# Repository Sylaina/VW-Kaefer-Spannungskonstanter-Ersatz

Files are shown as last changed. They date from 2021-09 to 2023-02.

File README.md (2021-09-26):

# VW-Käfer Spannungskonstanter-Ersatz für die Tankanzeige

Die hier gezeigte Schaltung dient dem Ersatz des im VW Käfer eingesetzten Spannungskonstanter für die Tankanzeige.

Der Füllstand des Tanks im Käfer ist mehr eine Schätzung als eine gute Anzeige. Ich habe in der Vergangenheit verschiedene Tankgeber und Tankanzeigen ausprobiert aber nie war die Tankanzeige zufriedenstellend einzustellen. Nach genauerer Analyse der verwendeten Technik ist, meiner Meinung nach, das Anzeigeinstrument das Problem. Der Tankgeber wird so im Grunde sogar heute noch in PKWs eingesetzt, hier betätigt ein Schwimmer ein Potentiometer (kurz Poti) welches seinen Widerstandswert dadurch ändert. Das Poti ist in Reihe geschaltet mit der Tankanzeige. Über Poti und Tankanzeige liegt eine konstante Spannung, durch die Widerstandsänderung des Potis ändert sich somit der Strom durch Poti und Tankanzeige. Dieser Strom erwärmt die Tankanzeige was letzten Endes die Tanknadel im Instrument bewegt.
Bei mir war das Problem, dass ich entweder die Leerstellung oder die Vollstellung richtig einstellen konnte. Ich habe es aber nie geschafft, die Leer- und Voll-Stellung gleichzeitig richtig einzustellen.

# Was macht die Schaltung?

Die hier vorgestellte Schaltung ersetzt den originalen Spannungskonstanter und prägt dem Anzeigeinstrument, abhängig von der Potistellung des Tankgebers, einen konstanten Strom ein. Lediglich die Widerstandswerte des Potis für Leer, Reserve (~5l Tankfüllung) und Voll müssen ermittelt werden sowie der Strom, den das Anzeigeinstrument für den Zeigerausschlag auf Tank Voll und Tank Leer aufnimmt.

Die Schaltung misst mit einem Mikrocontroller (AVR ATtiny85) den Widerstand des Potis vom Tankgeber und wandelt diesen Widerstand in einen proportionalen Strom für die Tankanzeige um.

Als Zusatz kann man eine LED oder ähnliches verbauen um das Erreichen der Reservefüllung zu visualisieren.

# Wie installiert man die Schaltung

Man entfernt den alten Spannungskonstanter und baut die Schaltung an der Stelle ein, in der auch der Spannungskonstanter eingebaut war. Dann muss nur noch das Instrument, die Schaltung und der Tankgeber angeschlossen werden und schon sollte alles funktionieren. Das Programm für den Mikrocontroller sowie die Gerberfiles für die Platine findet ihr in diesem github.

Viel Spass beim Nachbauen

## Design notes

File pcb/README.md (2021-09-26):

# Schaltplan und Gerberfiles für die Platine

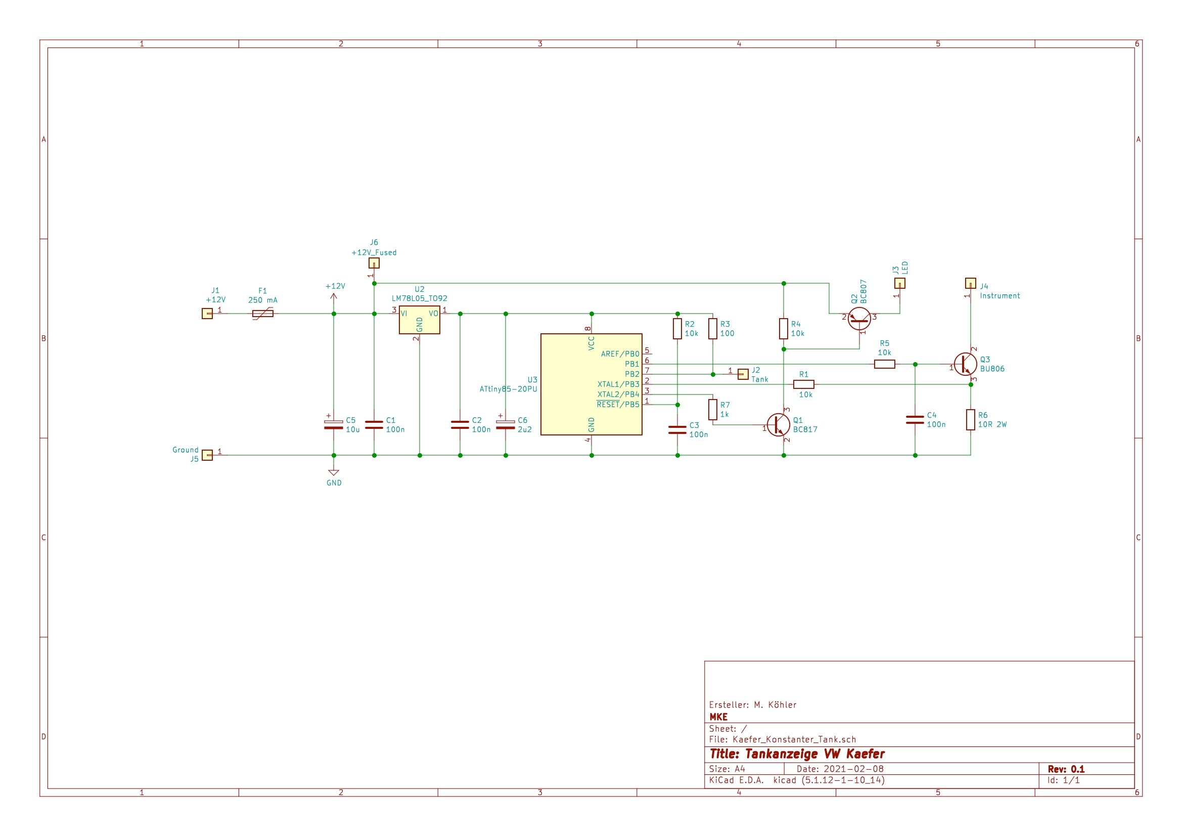
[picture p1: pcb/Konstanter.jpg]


# Preview der Platine

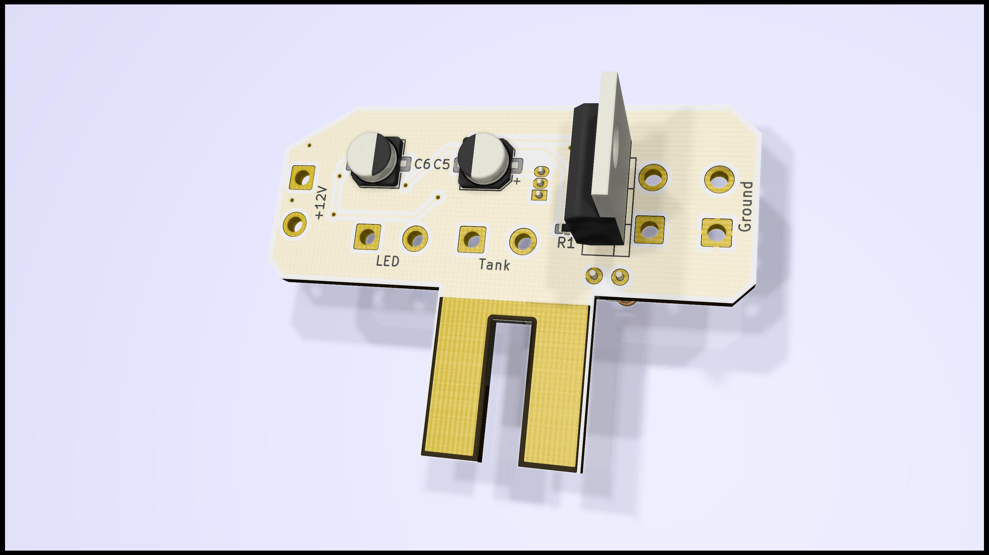
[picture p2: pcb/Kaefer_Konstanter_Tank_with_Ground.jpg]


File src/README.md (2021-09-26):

# Quellecode für den Mikrocontroller

Im makefile stehen alles nötigen Einstellungen um das Mikrocontrollerprogramm mit Hilfe des avr-gcc, avrdude 
und einem USBTiny auf einen ATtiny85 zu flashen.

# main.h

Das ist das einzige File, dass angefasst werden muss. In der Headerdatei werden die Widerstände des Potis
für die unterschiedlichen Tankfüllstände sowie die Ströme des Anzeigeninstruments festgelegt. Genaueres 
steht in den Kommentaren des Quelltextes.

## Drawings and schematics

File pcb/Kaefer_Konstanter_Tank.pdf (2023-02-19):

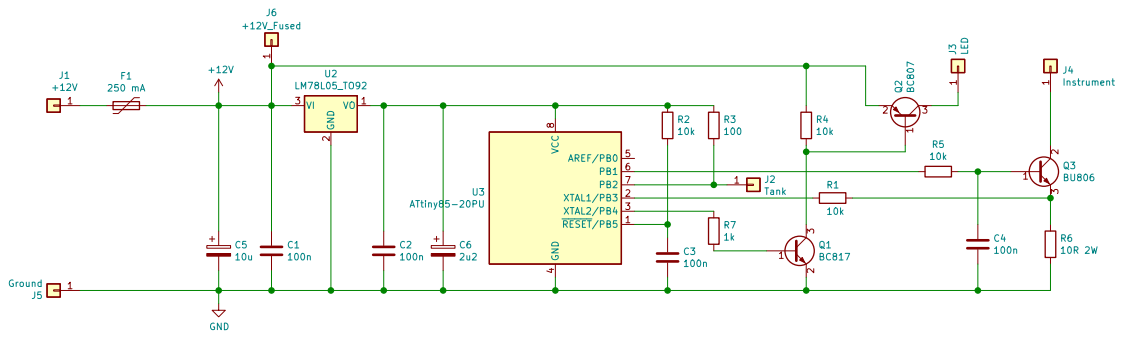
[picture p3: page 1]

Ersteller: M. Köhler
File: Kaefer_Konstanter_Tank.sch Sheet: / MKE

Id: 1/1 Title: Tankanzeige VW Kaefer

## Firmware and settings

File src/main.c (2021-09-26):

/* Tankanzeige fuer VW Kaefer und aehnliche Tankanzeigen
Tankgeber wird von einem ATtiny25/45/85 gemessen und generiert hierfuer einen
Strom fuer das Anzeige-Instrument. 
Die Widerstaende fuer Tank-leer, Tank-reserve und Tank-voll muessen gemessen werden.
Ebenso muss die Stromaufnahme fuer den jeweiligen Zeigerausschlag fuer
Tank leer und Tank voll gemessen werden.
 */

#include "main.h"
#include "pid.h"
#include "FloatingAverage.h"

// globale Variablen, werden in der Mainloop und/oder in verschiedenen 
// Interrupts (ISR()) genutzt

// Messkanal ADC
volatile uint8_t channel = 1;

// Feedback
volatile float actualCurrentFeedback = 0.0;

// Filter Current Feedback
volatile tFloatAvgFilter filterCurrentFeedback; 

// Messwertvariabel fuer den Tankgeber.
volatile float tankGeber = TANKSENSOREMPTY;

// Filter Tankgeber
volatile tFloatAvgFilter filterTankGeber;
   
int main(void)
{
	
    // Filter Tankgeber initialisieren
    InitFloatAvg((tFloatAvgFilter*)&filterTankGeber, 
    			 (tFloatAvgType)(TANKSENSOREMPTY*100.0) );
    // Filter currentFeedback initialisieren
    InitFloatAvg((tFloatAvgFilter*)&filterCurrentFeedback, 
    			  0);
    
	// Mikrocontroller einstellen
    setUpAvr();
    
    // Regler fuer die Anzeige deklarieren
    pid_controller_t tankController;
    
    // Regler initialisieren
    pid_init(KP,					// P-Faktor
    		 KI,					// I-Faktor
    		 KD,					// D-Faktor
    		 &tankController);		// Controller
    for(;;){
    	// Mikrocontroller schlafen legen
    	// wird vom ADC oder Watchdog aufgeweckt
        sleep_mode();
    	// Interrupts deaktivieren damit die aktuellen Messwerte nicht verfaelscht werden
    	// durch eine neue Messung (ADC ist Interrupt-gesteuert)
    	uint8_t sreg = SREG;
    	cli();
    	if(channel == 3){
			// Neuer Messwert liegt vor, Tankgeberwiderstand errechnen anhand des 
			// gleitenden Mittelwerts, Ergebnis in Ohm.
			tankGeber = M_SENSOR 
						* GetOutputValue((tFloatAvgFilter*)&filterTankGeber)/100.0 
						+ B_SENSOR;
    	}
    	// Tankgeber unter Reserve?
    	if(tankGeber > TANKSENSORLOW){
    		// optionale LED einschalten.
    		PORTB |= (1 << PB4);
    	} else if(tankGeber < (TANKSENSORLOW - 2.0)){
    		// tankGeber war groeßer als TANKSENSORLOW und muss nun um 2 Ohm
    		// kleiner sein (entspricht einem volleren Tank). Hysterese um ein 
    		// Flackern der LED zu vermeiden falls man an der Grenze ist.
    		PORTB &= ~(1 << PB4);
    	}
    	// Stromquelle einstellen fuer die Tankanzeige, Vorgabe in mV
    	// da Stromwerte in mA angegeben werden. If-Verschachtelung
    	// damit das Anzeigeinstrument innerhalb der zulaessigen Parameter betrieben wird
    	
    	if(tankGeber >= TANKSENSOREMPTY){
    		// Tank leer oder Kabel zum Tankgeber nicht angeschlossen.
    		OCR0B = (uint8_t)pid_compute((SHUNT * (M_SOURCE * TANKSENSOREMPTY + B_SOURCE)),
    							 		 GetOutputValue((tFloatAvgFilter*)&filterCurrentFeedback)/1000.0,
    							 		 &tankController);
    	}else if(tankGeber <= TANKSENSORFULL){
    		// Tank voll oder Kurzschluss.
    		OCR0B = (uint8_t)pid_compute((SHUNT * (M_SOURCE * TANKSENSORFULL + B_SOURCE)),
    							 		 GetOutputValue((tFloatAvgFilter*)&filterCurrentFeedback)/1000.0,
    							 		 &tankController);
    	}else {
    		// Tankgeber arbeitet im zulaessigen Bereich.
    		OCR0B = (uint8_t)pid_compute((SHUNT * (M_SOURCE * tankGeber + B_SOURCE)),
    							 		  GetOutputValue((tFloatAvgFilter*)&filterCurrentFeedback)/1000.0,
    							 		  &tankController);
    	}
    	// Interrupts wieder aktivieren fuer den naechsten Messzyklus
    	// durch zurueckschreiben von sreg
    	SREG = sreg;
        
        // Mikrocontroller aufgewacht durch ADC oder Watchdog
        // Watchdog Interruptmode wieder einschalten falls er aus ist damit es nicht zum
        // Reset kommt, dieser wird bei jedem Watchdog-Interrupt deaktiviert.
        // Sollte das Programm mal haengen bleiben wird der Watchdog den Mikrocontroller
        // reseten und somit neu starten. Dazu sollte es eigentlich nie kommen.
        if ( !(WDTCR & (1 << WDIE)) ){
        	WDTCR |= (1 << WDIE);
        }
    }
    return 0;   /* wird nie erreicht */
}

void setUpAvr(void){
	// watchdog reset 
	asm("wdr");
	// und ausschalten
	WDTCR = (1 << WDCE)|(1 << WDE);
	WDTCR &= ~(1 << WDE);
	
	// PLL einschalten für 16 MHz Mode
	// CKSEL wird auf 0001 eingestellt via fuses (Clocksource: PLL)
	PLLCSR |= (1 << PLLE);
	
	// Einstellen des ADC:
	// ADC-Prescaler auf 16 einstellen
	// Mikrocontroller laeuft auf 1 MHz, damit laeuft der ADC mit 62.5 kHz, Abtastrate
	// ergibt sich so zu ca. 2.5 kHz da abwechselnd zwei Kanaele gemessen werden.
	ADCSRA |= (1 << ADPS2);
	// und Referenzspannungquelle (hier interne 2.56V) waehlen, 
	// zugleich wird ADC-Messkanal 1 ausgewaehlt.
	ADMUX |= (1 << REFS2)|(1 << REFS1)|(1 << REFS0)|(1 << MUX0);
	// ADC starten
    ADCSRA |= (1 << ADEN)|(1 << ADSC);
    // und auf Abschluss der Konvertierung warten. 
    // Dummy-Read wegen Wahl/Aenderung der Referenzspannungsquelle!
    while (ADCSRA & (1 << ADSC)) {
        
    }
    // ADC starten und Interrupt einschalten
    ADCSRA |= (1 << ADIE)|(1 << ADSC);
    
    // PWM einstellen:
    // Fast-PWM Mode und OC0B wird gewaehlt.
    TCCR0A |= (1 << WGM00)|(1 << WGM01)|(1 << COM0B1);
    TCCR0B |= (1 << CS00);
    // PWM Ausgangspin einstellen auf Ausgang fuer OC0B.
    DDRB |= (1 << PB1);
    PORTB &= ~(1 << PB1);
    
    // LED/Schaltkontakt fuer Tankreserve.
    // Anschluss standardmaeßig nicht bestueckt,
    // Funktionalitaet aber vorhanden.
    // Der Kontakt schaltet die Versorgung des Konstanters durch
    // und kann mit bis zu 0.5A maximal belastet werden.
    DDRB |=(1 << PB4);
    PORTB &= ~(1 << PB4);
    
    // nicht benoetigte Module abschalten, spart Strom wenngleich das hier
    // verschwindet gering sein wird.
    // Deaktivieren von Timer1 und USI-Modul
    PRR |= (1 << PRTIM1)|(1 << PRUSI);
    // Deaktivieren des Analog Comparators
    ACSR |= (1 << ACD);
    
    // Schlafmodus des Mikrocontrollers einstellen.
    // Da die Timer fuer die PWM benoetigt werden ist nur IDLE moeglich,
    // schon bei SLEEP_MODE_ADC werden die Clocks fuer die PWM deaktiviert.
    // Folge waere: PWM arbeitet nicht mehr, Tankanzeige bekommt den falschen
    // Strom eingepraegt und somit ist die Anzeige ansich falsch.
    set_sleep_mode(SLEEP_MODE_IDLE);
    
    // Watchdog einstellen auf 1s,
    WDTCR |= (1 << WDP2)|(1 << WDP1);
    // Interrupt konfigurieren
    WDTCR |= (1 << WDIE);
    // und einschalten
    WDTCR |= (1 << WDE);

    // enable interrupts
    sei();
}
ISR(ADC_vect){
	switch(channel){
		case 1:
			// tankGeber, aktuelle Spannung ueber dem Tankgeber,
			// der Widerstand wird in der Mainloop berechnet.
			AddToFloatAvg((tFloatAvgFilter*)&filterTankGeber, 
						  (tFloatAvgType)(ADC * (VREF / ADC_RESOLUTION) * 100.0));
			// Kanalwechsel, beim naechsten Aufruf wird die Spannung ueber dem 
			// Shunt zur Strommessung gemessen.
			channel = 3;
			break;
		case 3:
			// Feedback, aktuelle Spannung ueber dem Shunt.
			AddToFloatAvg((tFloatAvgFilter*)&filterCurrentFeedback, 
						  (tFloatAvgType)(ADC * (VREF / ADC_RESOLUTION) * 1000.0));
			// Kanalwechsel, beim naechsten Aufruf wird die Spannung ueber dem
			// Tankgeber gemessen.
			channel = 1;
			break;
		default:
			channel = 1;
			break;
	}
	ADMUX = (ADMUX & ~(0x0f)) | (channel & 0x0f);
	// ADC wieder starten fuer den naechsten Durchlauf.
	ADCSRA |= (1 << ADSC);
}

ISR(WDT_vect){
	// Watchdog Interrupt wird jede Sekunde aufgerufen um den Mikrocontroller aufzuwecken.
	// Watchdog Interrupt ist somit erstmal deaktiviert, wird in der Mainloop wieder
	// aktiviert damit es nicht zu einem Reset durch den Watchdog kommt.
}

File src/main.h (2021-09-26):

//
//  main.h

/* TODO: Tankgeber und Tankanzeige vermessen, Ergebnisse hier eintragen */

// Widerstandswerte des Tankgebers bei entsprechenden Fuellstaenden in Ohm
#define TANKSENSOREMPTY	47.0	// Tank leer
#define TANKSENSORLOW	40.0	// Tank Reserve (5l-10l im Tank)
								// wird nur fuer die optionale LED benoetigt.
#define TANKSENSORFULL	 9.0	// Tank voll

// Stromaufnahme des Instruments, 
// Zeiger auf den entsprechenden Positionen, Strom in Ampere
#define TANKEMPTY		0.020	// Tankanzeige leer
#define TANKFULL		0.160	// Tankanzeige voll, sollte deutlich weniger als 500mA 
    							// sein ansonsten ist wahrscheinlich das Instrument defekt

/* TODO: Wird die Schaltung nicht veraendert dann ab hier keine Aenderungen vornehmen */

// Parameter fuer den Regler
// Instrument ist recht träge, daher hier keine Optimierung noetig.
#define KP				2.0
#define KI				1.0
#define KD				0.0

// Die folgenden Werte nur an den Schaltplan anpassen
// Aenderungen sind hier idR nicht noetig.
#define RV				100.0
#define SHUNT			10.0 
#define VCC				5.000
#define VREF			2.56
#define ADC_RESOLUTION	1024.0

// Hilfsvariablen fuer die jeweiligen Kennlinien, Kennlinien wurden als Graden
// approximiert. Das stimmt zwar nicht exakt aber es genuegt fuer die Tankanzeige.
#define M_SENSOR	((TANKSENSOREMPTY - TANKSENSORFULL) / (VCC * ((TANKSENSOREMPTY / (TANKSENSOREMPTY + RV)) - (TANKSENSORFULL / (TANKSENSORFULL + RV)))))
#define B_SENSOR	(TANKSENSOREMPTY - (VCC * TANKSENSOREMPTY / (TANKSENSOREMPTY + RV) * M_SENSOR))
#define M_SOURCE	((TANKFULL - TANKEMPTY) / (TANKSENSORFULL - TANKSENSOREMPTY))
#define B_SOURCE	(TANKEMPTY - (M_SOURCE * TANKSENSOREMPTY))

#ifndef main_h
#define main_h
#include <avr/io.h>
#include <avr/sleep.h>
#include <avr/interrupt.h>

void setUpAvr(void);

#endif /* main_h */

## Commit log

2021-09-26 Schaltplan und Gerberfiles
2021-09-26 Schematic as picture
